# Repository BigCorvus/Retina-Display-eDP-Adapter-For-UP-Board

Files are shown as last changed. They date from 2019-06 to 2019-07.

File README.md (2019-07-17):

# Retina-Display-eDP-Adapter-For-UP-Board
This project contains the design files for an eDP adapter and backlight driver for iPad 3 retina displays. These have  2,048 by 1,536 (2K) resolution and are 9.7 inch in diagonal. They can be ripped out of bricked or defective ipads or bought as new replacement parts for about 40$. With an adapter such as this one http://abusemark.com/store/index.php?main_page=product_info&products_id=53&zenid=li1so9u2k8e7n3u8q3j7j0uqg2 you should be able to use 7.9 inch iPad mini screens too. Capacitive touch overlays for the 9.7 inch screens with i2c to USB converters can be found on aliexpress.

The adapter and backlight driver board is based on the Adafruit Qualia driver (https://learn.adafruit.com/qualia-high-res-displayport-desktop-monitor?view=all#overview). The PCB has been made smaller and the 3.3V buck regulator, ATtiny backlight control as well as the bulky display port connector have been removed since most single board computers already provide 3.3V as well as backlight control. The board can be used for any single board computer with eDP interface by soldering bare wires to the appropriate connector. I'm using this with an UP core with Windows 10. After some automatic driver installations in the background, the PWM dimming function started to work perfectly well. The retina display connectors can be found on ebay and are quite cheap. And yes, they can be hand soldered. Just use enough good quality flux.

UP_with_retina

UP_with_retina_working

A .brd file for a connector for CN31 of the UP board or UP core is included, which can be manufactured by the new OSH Park flex service and costs next to nothing. The 5 differential pairs as well as wires for the 3.3V supply and control lines are soldered directly to the flex PCB using 30AWG solid core wires. Note that the flex PCB seems to be a little too thick for the connector to close properly, but the friction fit seems to be sufficient. 

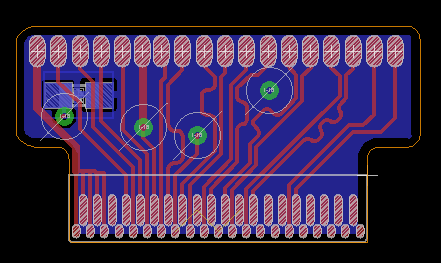
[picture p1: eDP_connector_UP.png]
UP_eDP_connector


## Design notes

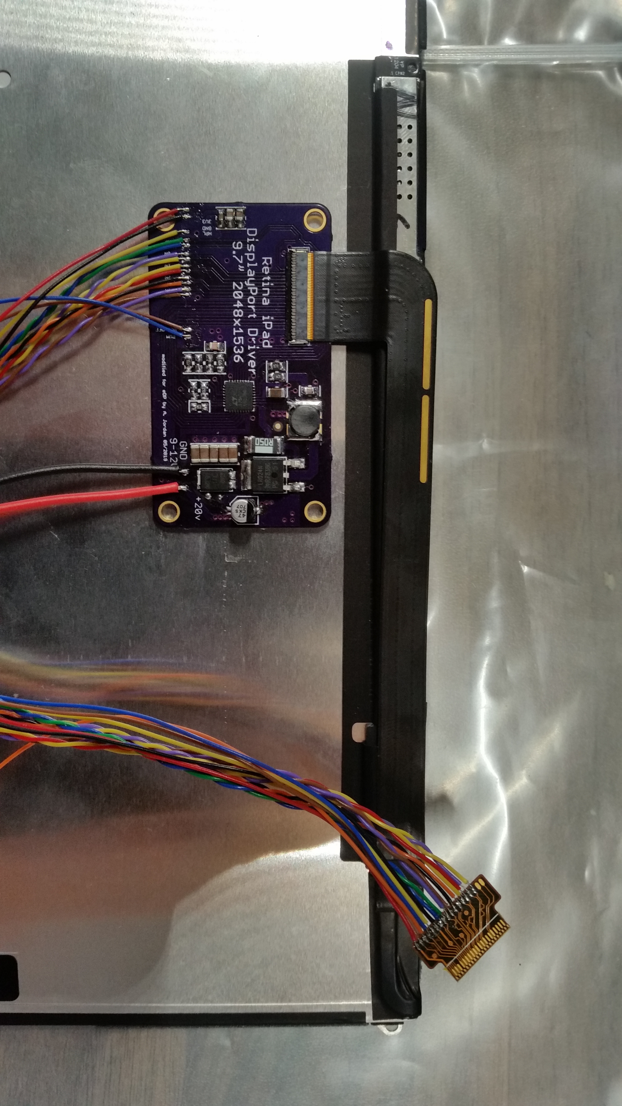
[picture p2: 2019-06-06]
driverPCBretina.jpg

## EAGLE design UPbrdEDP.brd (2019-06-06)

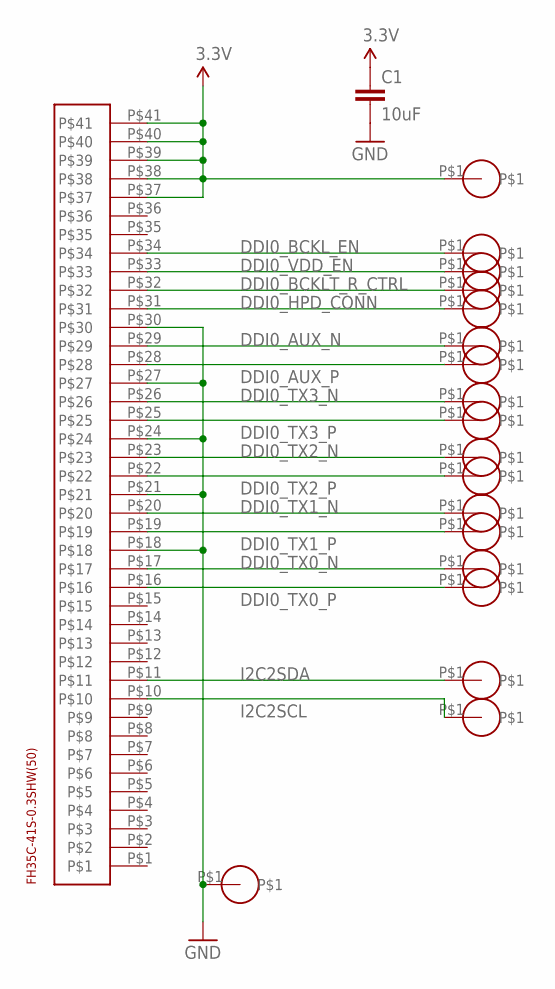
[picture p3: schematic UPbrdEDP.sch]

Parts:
C1: 10uF; 0603-CAP
U$1: FH35C-41S-0.3SHW(50)
U$2, U$3, U$4, U$5, U$6, U$7, U$8, U$9, U$10, U$11, U$12, U$13, U$14, U$15, U$16, U$17, U$18, U$19: SOLDERPAD

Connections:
3.3V: C1.1, U$1.P$37, U$1.P$38, U$1.P$39, U$1.P$40, U$1.P$41, U$18.P$1
DDI0_AUX_N: U$1.P$29, U$13.P$1
DDI0_AUX_P: U$1.P$28, U$12.P$1
DDI0_BCKLT_R_CTRL: U$1.P$32, U$15.P$1
DDI0_BCKL_EN: U$1.P$34, U$17.P$1
DDI0_HPD_CONN: U$1.P$31, U$14.P$1
DDI0_TX0_N: U$1.P$17, U$5.P$1
DDI0_TX0_P: U$1.P$16, U$4.P$1
DDI0_TX1_N: U$1.P$20, U$7.P$1
DDI0_TX1_P: U$1.P$19, U$6.P$1
DDI0_TX2_N: U$1.P$23, U$9.P$1
DDI0_TX2_P: U$1.P$22, U$8.P$1
DDI0_TX3_N: U$1.P$26, U$11.P$1
DDI0_TX3_P: U$1.P$25, U$10.P$1
DDI0_VDD_EN: U$1.P$33, U$16.P$1
GND: C1.2, U$1.P$18, U$1.P$21, U$1.P$24, U$1.P$27, U$1.P$30, U$19.P$1
I2C2SCL: U$1.P$10, U$3.P$1
I2C2SDA: U$1.P$11, U$2.P$1

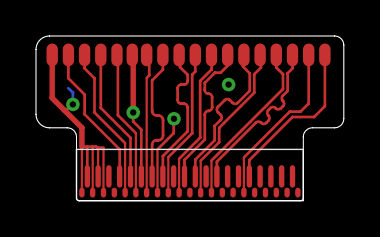
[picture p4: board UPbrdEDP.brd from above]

Board: 2 copper layers, 17.1 x 9.2 mm, 20 parts (1 on the bottom side), 18 nets.

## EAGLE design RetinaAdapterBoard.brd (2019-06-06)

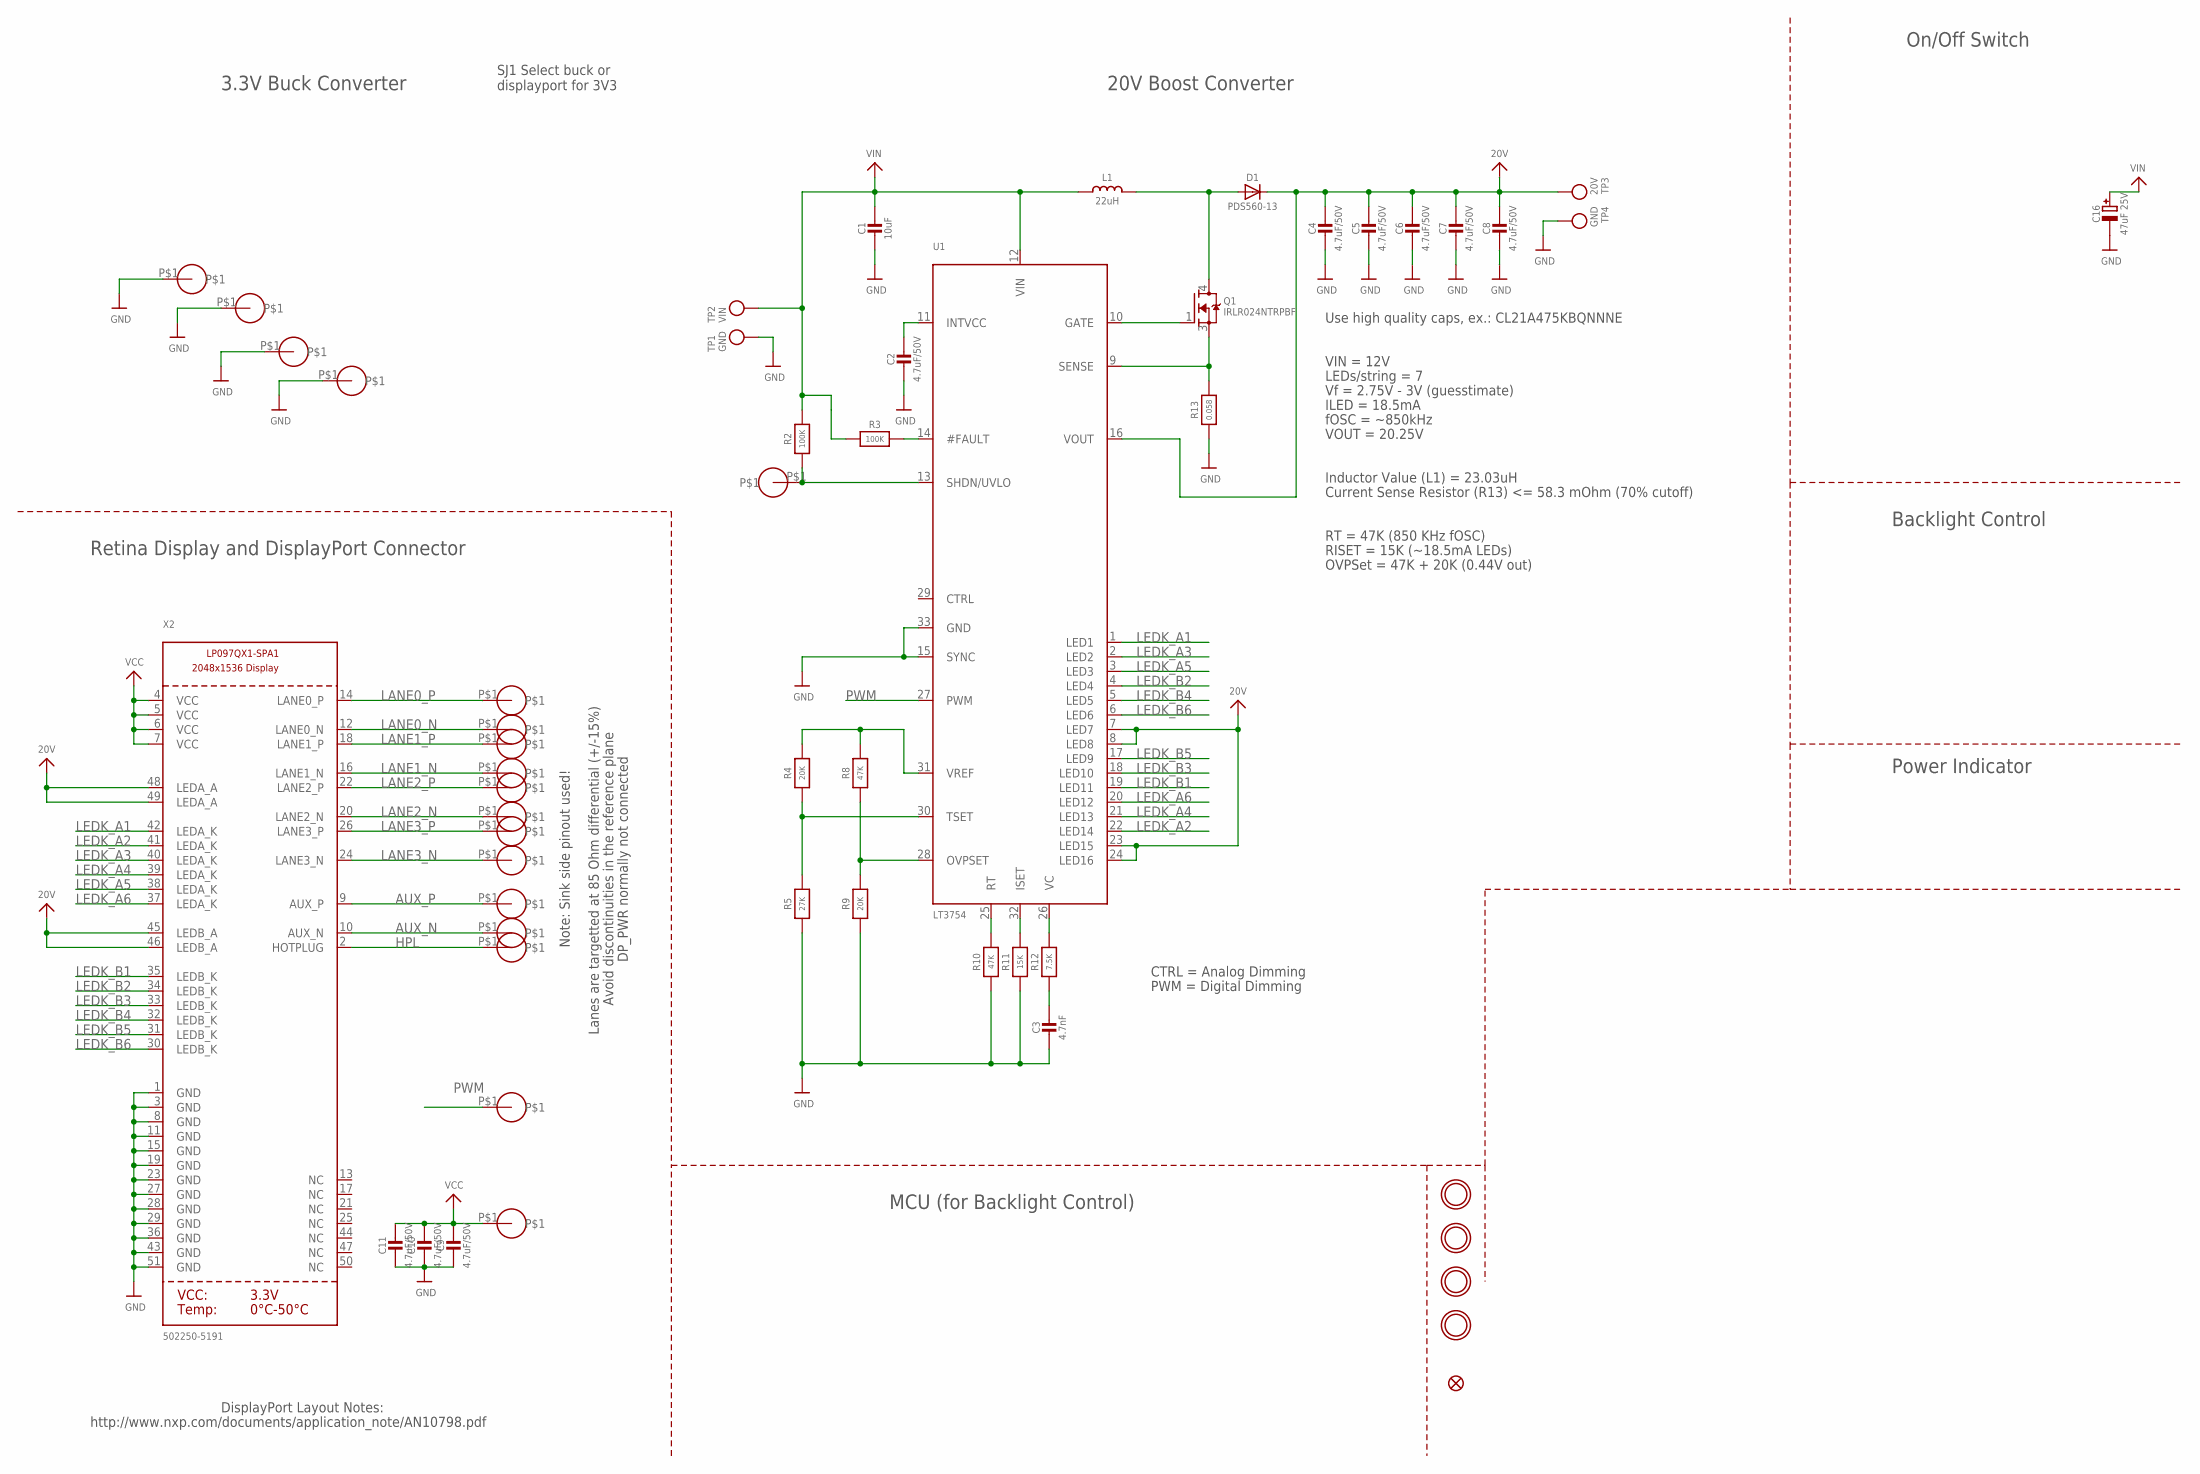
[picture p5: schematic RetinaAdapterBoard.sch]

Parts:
C1: 10uF; _0805
C2, C4, C5, C6, C7, C8, C9, C10, C11: 4.7uF/50V; _0805
C3: 4.7nF; _0805
C16: 47uF 25V; PANASONIC_C
D1: PDS560-13; POWERDI-5
FID3: FIDUCIAL""; FIDUCIAL_1MM
L1: 22uH; INDUCTOR_6X6MM_SUMIDA_CDRH5D28
Q1: IRLR024NTRPBF; DPAK
R2, R3: 100K; _0805
R4, R9: 20K; _0805
R5: 27K; _0805
R8, R10: 47K; _0805
R11: 15K; _0805
R12: 7.5K; _0805
R13: 0.058; 2512
TP1, TP4: GND; TESTPOINT_ROUND_1MM
TP2: VIN; TESTPOINT_ROUND_1MM
TP3: 20V; TESTPOINT_ROUND_1MM
U1: LT3754; QFN32_5MM
U$1, U$4, U$9, U$10, U$13, U$15, U$43, U$46, U$47, U$48, U$49, U$50, U$51, U$52, U$53, U$54, U$55, U$57: SOLDERPAD
U$11, U$32, U$33, U$34: MOUNTINGHOLE3.0THIN; MOUNTINGHOLE_3.0_PLATEDTHIN
X2: 502250-5191; FPC_51PIN_502250-5191_EXT

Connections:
20V: C4.1, C5.1, C6.1, C7.1, C8.1, D1.C, TP3.P$1, U1.7 (LED7), U1.8 (LED8), U1.16 (VOUT), U1.23 (LED15), U1.24 (LED16), X2.45 (LEDB_A), X2.46 (LEDB_A), X2.48 (LEDA_A), X2.49 (LEDA_A)
AUX_N: U$1.P$1, X2.10 (AUX_N)
AUX_P: U$43.P$1, X2.9 (AUX_P)
GND: C1.2, C2.2, C3.2, C4.2, C5.2, C6.2, C7.2, C8.2, C9.2, C10.2, C11.2, C16.-, R5.1, R9.1, R10.1, R11.1, R13.1, TP1.P$1, TP4.P$1, U1.15 (SYNC), U1.33 (GND), U$10.P$1, U$13.P$1, U$15.P$1, U$55.P$1, X2.1 (GND), X2.3 (GND), X2.8 (GND), X2.11 (GND), X2.15 (GND), X2.19 (GND), X2.23 (GND), X2.27 (GND), X2.28 (GND), X2.29 (GND), X2.36 (GND), X2.43 (GND), X2.51 (GND)
HPL: U$54.P$1, X2.2 (HOTPLUG)
LANE0_N: U$52.P$1, X2.12 (LANE0_N)
LANE0_P: U$53.P$1, X2.14 (LANE0_P)
LANE1_N: U$50.P$1, X2.16 (LANE1_N)
LANE1_P: U$51.P$1, X2.18 (LANE1_P)
LANE2_N: U$48.P$1, X2.20 (LANE2_N)
LANE2_P: U$49.P$1, X2.22 (LANE2_P)
LANE3_N: U$46.P$1, X2.24 (LANE3_N)
LANE3_P: U$47.P$1, X2.26 (LANE3_P)
LEDK_A1: U1.1 (LED1), X2.42 (LEDA_K)
LEDK_A2: U1.22 (LED14), X2.41 (LEDA_K)
LEDK_A3: U1.2 (LED2), X2.40 (LEDA_K)
LEDK_A4: U1.21 (LED13), X2.39 (LEDA_K)
LEDK_A5: U1.3 (LED3), X2.38 (LEDA_K)
LEDK_A6: U1.20 (LED12), X2.37 (LEDA_K)
LEDK_B1: U1.19 (LED11), X2.35 (LEDB_K)
LEDK_B2: U1.4 (LED4), X2.34 (LEDB_K)
LEDK_B3: U1.18 (LED10), X2.33 (LEDB_K)
LEDK_B4: U1.5 (LED5), X2.32 (LEDB_K)
LEDK_B5: U1.17 (LED9), X2.31 (LEDB_K)
LEDK_B6: U1.6 (LED6), X2.30 (LEDB_K)
unnamed: C2.1, U1.11 (INTVCC)
unnamed: R2.1, U1.13 (SHDN/UVLO), U$9.P$1
unnamed: R3.2, U1.14 (#FAULT)
unnamed: R12.2, U1.26 (VC)
unnamed: C3.1, R12.1
unnamed: R4.1, R5.2, U1.30 (TSET)
unnamed: R4.2, R8.2, U1.31 (VREF)
unnamed: R8.1, R9.2, U1.28 (OVPSET)
unnamed: R10.2, U1.25 (RT)
unnamed: R11.2, U1.32 (ISET)
unnamed: Q1.3 (S), R13.2, U1.9 (SENSE)
unnamed: Q1.1 (G), U1.10 (GATE)
unnamed: D1.A1 (A), D1.A2 (A), L1.P$2 (2), Q1.4 (D)
PWM: U1.27 (PWM), U$57.P$1
VCC: C9.1, C10.1, C11.1, U$4.P$1, X2.4 (VCC), X2.5 (VCC), X2.6 (VCC), X2.7 (VCC)
VIN: C1.1, C16.+, L1.P$1 (1), R2.2, R3.1, TP2.P$1, U1.12 (VIN)

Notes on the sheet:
Note: Sink side pinout used!
DP_PWR normally not connected
Lanes are targetted at 85 Ohm differential (+/-15%)
Avoid discontinuities in the reference plane
DisplayPort Layout Notes:
http://www.nxp.com/documents/application_note/AN10798.pdf
Use high quality caps, ex.: CL21A475KBQNNNE
Inductor Value (L1) = 23.03uH
VIN = 12V
LEDs/string = 7
Vf = 2.75V - 3V (guesstimate)
ILED = 18.5mA
VOUT = 20.25V
fOSC = ~850kHz
Current Sense Resistor (R13) <= 58.3 mOhm (70% cutoff)
RT = 47K (850 KHz fOSC)
RISET = 15K (~18.5mA LEDs)
OVPSet = 47K + 20K (0.44V out)
20V Boost Converter
MCU (for Backlight Control)
On/Off Switch
Retina Display and DisplayPort Connector
3.3V Buck Converter
CTRL = Analog Dimming
PWM = Digital Dimming
Backlight Control
Power Indicator
SJ1 Select buck or displayport for 3V3

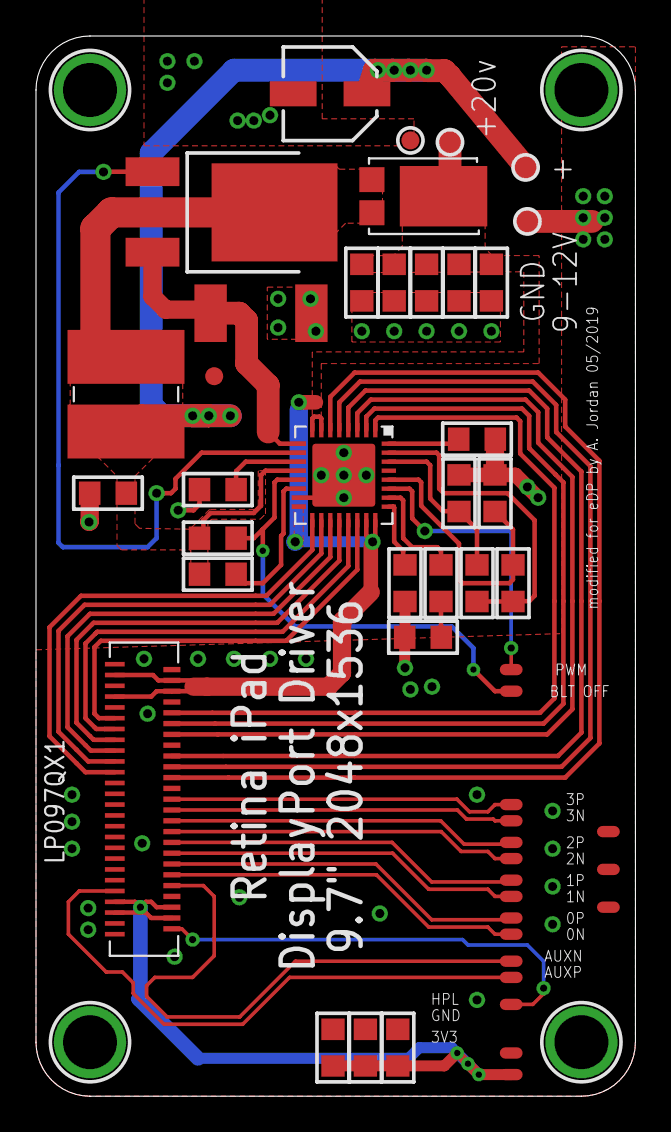
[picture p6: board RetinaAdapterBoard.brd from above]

Board: 2 copper layers, 33.3 x 58.9 mm, 54 parts (0 on the bottom side), 41 nets.

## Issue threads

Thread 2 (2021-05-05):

skip adapter?

bam80, 2021-05-05:
Hi, thanks for your project, looks attractive.
Could you advice me if I could find any eDP display matrix capable to connect to UP board's eDP directly, without any active components?

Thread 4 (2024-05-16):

Is there a parts BOM?

Stokestack, 2024-05-16:
It would be great to have a part list to go with the circuit board. Am I overlooking it, or is this not here?

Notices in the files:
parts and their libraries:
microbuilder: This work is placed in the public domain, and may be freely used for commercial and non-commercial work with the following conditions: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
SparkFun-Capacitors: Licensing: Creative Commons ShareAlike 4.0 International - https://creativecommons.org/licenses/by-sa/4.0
